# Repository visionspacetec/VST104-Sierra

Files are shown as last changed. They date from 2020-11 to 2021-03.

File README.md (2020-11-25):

# VST104 Board Sierra - single MCU OBC for PC104
This repository contains the KiCad project and other documents created during the development of Board Sierra under [VST104 project](https://github.com/visionspacetec/VST104/). This PC104 CubeSats module is a single redundant onboard computer designed to fulfill most space industry requirements.

<p align="center">
  <br>
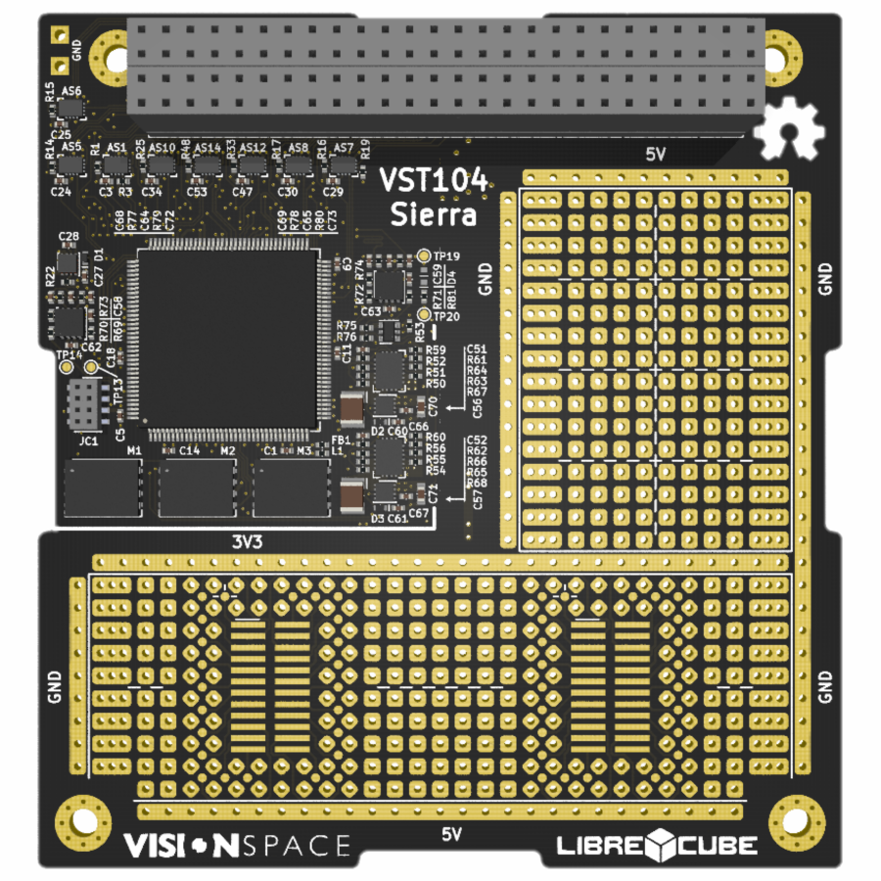
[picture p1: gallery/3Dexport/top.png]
  
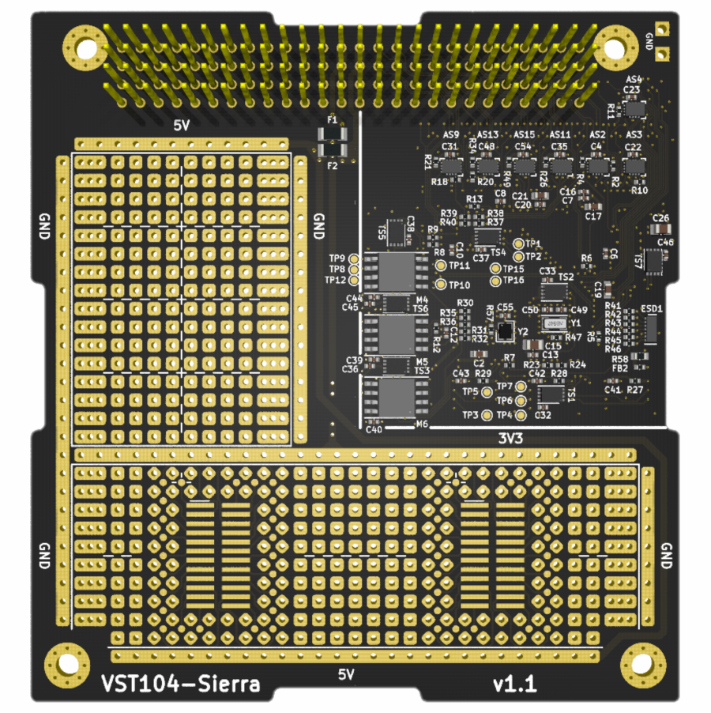
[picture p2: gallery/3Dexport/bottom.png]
  
  <br><br>
  <b>Fig 1.</b> Board Sierra OBC module 3D visualisation top (left) and bottom (right) side.
  <br><br>
</p>

## Basic specifications
* **`processor:`** This onboard computer is driven by state of the art, ultra-low-power **STM32L496 ARM® Cortex®-M4 core** microcontroller. This MCU is capable of running **up to 78[MHz]** in our design.
* **`clock:`** Microcontroller is driven by two external clock sources. Low-speed **external 32.768[kHz] oscillator** (LSE) and high-speed **external 26[MHz] oscillator** (HSE). The MCU is capable of temporarily disable the HSE to achieve better power consumption.
* **`memory:`** Two groups of triple redundant external memories are available for data storage and processing. The triple redundancy was chosen as an effective measure against single event effects. The first memory group is **256 [Mbit] Flash** wired via Quad-SPI interface and the second one is **2 [Mbit] F-RAM** using SPI.
* **`peripherals:`** This module can communicate with other CubeSat subsystems using a wide variety of redundant protocols. The main PC104 header is capable of connecting to **2x CAN-BUS, 3x I2C, 4x UART** (with CTS and RTS), **2xSPI** (2 enables each), and **22 general purpose** A/D I/O pins. All of the listed peripherals are wired thru separated isolators controlled by the MCU. On top of that, separate traces are used for system check and maintenance signals, such as: WatchDog, KillSwitch, CPUmode, Sync, FaultCollector. The pinout of these interferences is shown in figure 3.
* **`connectivity:`** A user can program and debug this OBC using **SWI and/or UART interface**. These interfaces are accessible on the board's edge on a separate connector with integrated electrostatic discharge protection circuitry. The SWI interface is compatible with STM ST-LINK series programmers (including SWO pin).

<p align="center">
  <br>
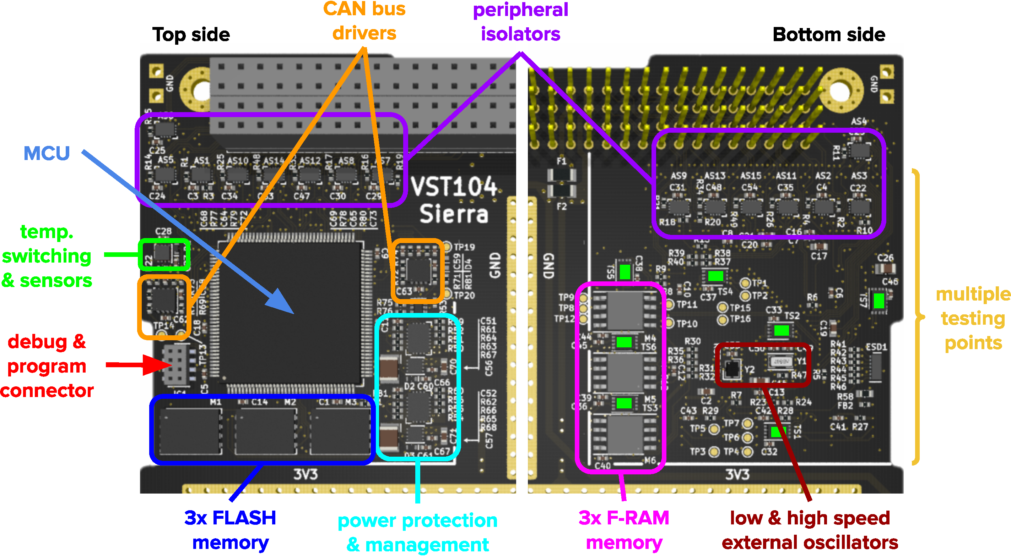
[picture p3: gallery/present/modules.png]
  
  <br><br>
  <b>Fig 2.</b> Important circuitry groups on top (left) and bottom (right) side of the module.
  <br><br>
</p>

## Features
* All used components are suitable for the space environment, following: mechanical failure qualifications **AEC-Q100 or AEC-Q200** and **military rated** operational temperatures (-40°C to +125°C).
* This module requires two separate power lines of 3.3[V] and 5[V] ratings. A **robust power management** circuitry is present separately on these lines, providing various functionalities. Namely: tunable over and under-voltage protection, tunable over-current protection, amplified current monitoring output, kill switching, or simultaneous power down.
* A group of **seven I2C temperature sensors** is spread over the entire module. These sensors are used to check the temperature of essential submodules such as: 2x power management, 2x CAN-BUS drivers, 2x external memories, and 1x STM32 microcontroller. Also, the MCU can power these sensors in case of power saving or latch-up events.
* A compact design was one of our priorities during the development of this module. As a result, this module's full three-fourths are left empty and ready to **accommodate any required payload**. This current version is the payload sector represented as a universal soldering array with exposed power lines (outside the power management).

<p align="center">
  <br>
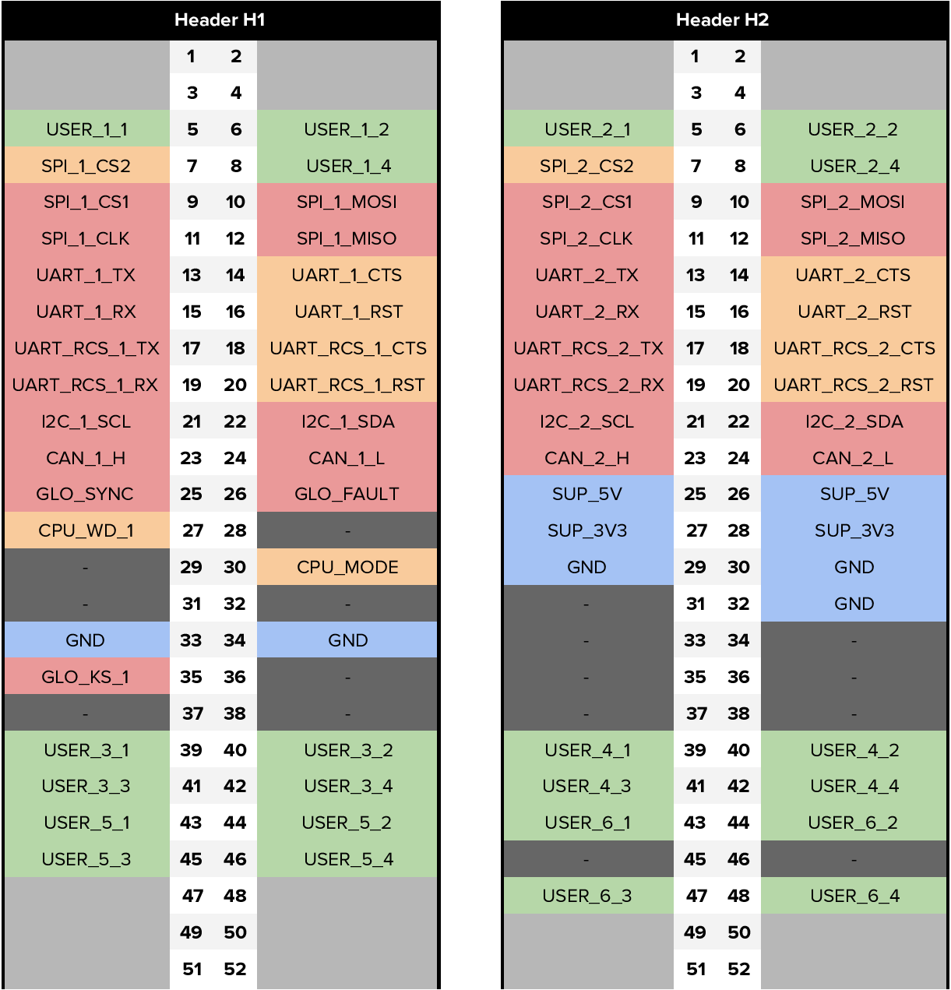
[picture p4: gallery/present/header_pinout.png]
  
  <br><br>
  <b>Fig 3.</b> PC104 header pinout supported by this OBC module.
  <br><br>
</p>

## Debug & Program connector
A separate 2x4 female format connector on the board's left side is used for debugging and programming.  SWI and UART5 interfaces of the boarded STM32 microprocessor are wired to this connector, as shown in figure 4. This interface is fully compatible with STM ST-Link family programmers. 

<p align="center">
  <br>
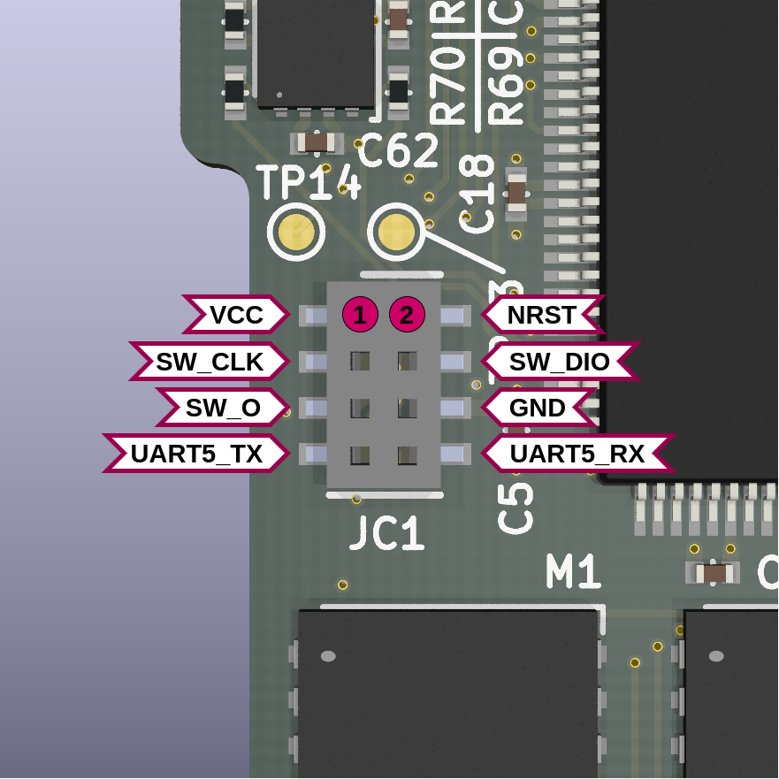
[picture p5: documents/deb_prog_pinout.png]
  
  <br><br>
  <b>Fig 4.</b> Pinout of the debug and program connector.
  <br><br>
</p>

## References
The design of this PC 104 SBC module was processed under evaluation of the following documents:

[1] : [STM32L496xx datasheet](https://www.st.com/resource/en/datasheet/stm32l496ae.pdf)  
[2] : [STM32L496xx getting started manual](https://www.st.com/resource/en/application_note/dm00125306-getting-started-with-stm32l4-series-and-stm32l4-series-hardware-development-stmicroelectronics.pdf)  
[3] : [STM32 oscillator design guide](https://www.st.com/resource/en/application_note/cd00221665-oscillator-design-guide-for-stm8afals-stm32-mcus-and-mpus-stmicroelectronics.pdf)  
[4] : [STM32 Quad-SPI interface](https://www.st.com/resource/en/application_note/dm00227538-quadspi-interface-on-stm32-microcontrollers-and-microprocessors-stmicroelectronics.pdf)  
[5] : [Common mode chokes in CAN networks](https://www.ti.com/lit/an/slla271/slla271.pdf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,results%20in%20the%20CAN%20network.&text=Following%20the%20choke%20in%20the,is%20the%20optional%20termination%20circuit.)  
[6] : [Isolated CAN systems with protection](https://www.ti.com/lit/an/slla419/slla419.pdf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,ratings%20up%20to%20several%20kilowatts.)

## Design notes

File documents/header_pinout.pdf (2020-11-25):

Header H1 | | Header H2
| 1 2 | | | 1 2
| 3 4 | | | 3 4
USER_1_1 | 5 6 | USER_1_2 | USER_2_1 | 5 6 | USER_2_2
SPI_1_CS2 | 7 8 | USER_1_4 | SPI_2_CS2 | 7 8 | USER_2_4
SPI_1_CS1 | 9 | 10 | SPI_1_MOSI | SPI_2_CS1 | 9 | 10 | SPI_2_MOSI
SPI_1_CLK | 11 | 12 | SPI_1_MISO | SPI_2_CLK | 11 | 12 | SPI_2_MISO
UART_1_TX | 13 | 14 | UART_1_CTS | UART_2_TX | 13 | 14 | UART_2_CTS
UART_1_RX | 15 | 16 | UART_1_RST | UART_2_RX | 15 | 16 | UART_2_RST
UART_RCS_1_TX | 17 | 18 | UART_RCS_1_CTS | UART_RCS_2_TX | 17 | 18 | UART_RCS_2_CTS
UART_RCS_1_RX | 19 20 | UART_RCS_1_RST | UART_RCS_2_RX | 19 20 | UART_RCS_2_RST
I2C_1_SCL | 21 22 | I2C_1_SDA | I2C_2_SCL | 21 22 | I2C_2_SDA
CAN_1_H | 23 24 | CAN_1_L | CAN_2_H | 23 24 | CAN_2_L
GLO_SYNC | 25 26 | GLO_FAULT | SUP_5V | 25 26 | SUP_5V
CPU_WD_1 | 27 28 | - | SUP_3V3 | 27 28 | SUP_3V3
-- | 29 30 | CPU_MODE | GND | 29 30 | GND
| 31 32 | - | - | 31 32 | GND
GND | 33 34 | GND | - | 33 34 | -
GLO_KS_1 | 35 36 | - | - | 35 36 | -
- | 37 38 | - | - | 37 38 | -
USER_3_1 USER_3_3 USER_5_1 USER_5_3 | 39 40 | USER_3_2 | USER_4_1 | 39 40 | USER_4_2
| 41 42 | USER_3_4 | USER_4_3 | 41 42 | USER_4_4
| 43 44 | USER_5_2 | USER_6_1 | 43 44 | USER_6_2
| 45 46 | USER_5_4 | - | 45 46 | -
| 47 48 | | USER_6_3 | 47 48 | USER_6_4
| 49 50 | | | 49 50
| 51 52 | | | 51 52

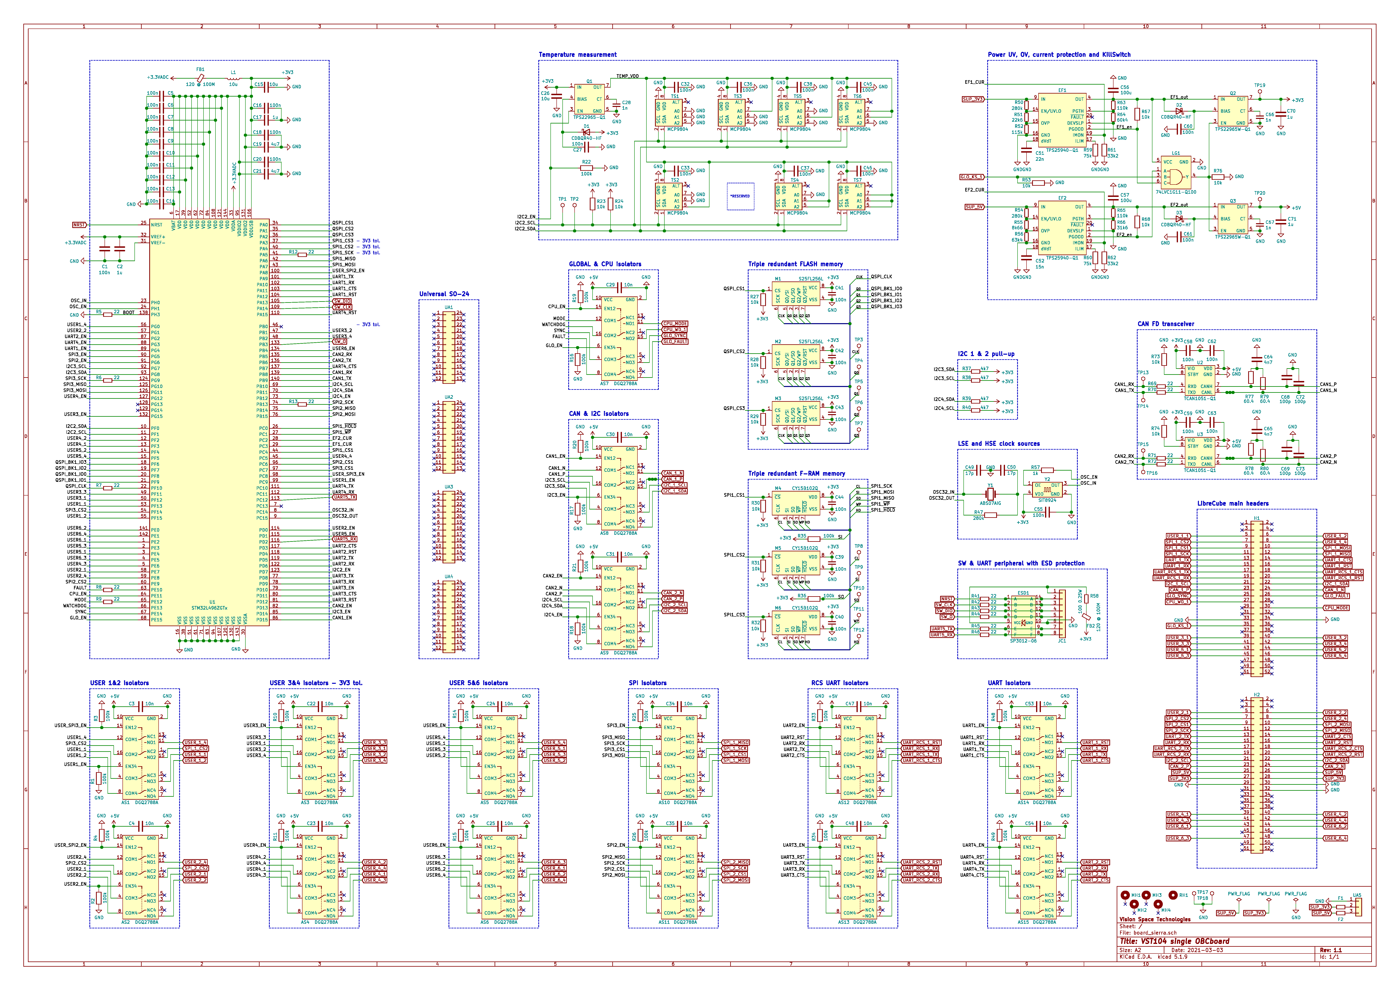
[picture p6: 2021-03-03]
gallery/present/schematic.png

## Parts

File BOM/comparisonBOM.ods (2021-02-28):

 |  |  |  | Temperature and automotive certified |  |  |  | Uncertified replacement/variant
customer no | description | schematic | qty. | manufacturer no | Mouser no | price | ext. | manufacturer no | Mouser no | price | ext. | delta | type | main differences
mcu | microcontroller | U1 | 1 | STM32L496ZGT3 | 511-STM32L496ZGT3 | 11.51 | 11.51 | STM32L496ZGT3 | 511-STM32L496ZGT3 | 11.51 | 11.51 | 0 | same | N/A
clo_lse | LSE crystal | Y1 | 1 | ABS07AIG-32.768kHz-6-1-T | 815-S07AIG32.768-61T | 0.983 | 0.983 | SC32S-7PF20PPM | 628-SC32S-7PF20PPM | 0.382 | 0.382 | -0.601 | repl. | capacitance, tolerance, qual.
clo_hse | HSE oscillator | Y2 | 1 | SIT8924AA-72-XXE-26.000000G | 788-8924AA-72XXE26G | 2.68 | 2.68 | MC2016Z26.0000C19XSH | 346-MC2016Z26.0000C1 | 1.14 | 1.14 | -1.54 | repl. | stability, qual.
per_tmp | temperature sen. | TS* | 7 | MCP9804-E/MC | 579-MCP9804-E/MC | 1.42 | 9.94 | MCP9808T-E/MC | 579-MCP9808T-E/MC | 0.957 | 6.699 | -3.241 | variant | accuracy
per_isol | analog isolator | AS* | 15 | DGQ2788AEN-T1-GE4 | 78-DGQ2788AEN-T1-GE4 | 0.688 | 10.32 | DGQ2788AEN-T1-GE4 | 78-DGQ2788AEN-T1-GE4 | 0.688 | 10.32 | 0 | same | N/A
per_can | CAN bus driver | U[2,3] | 2 | TCAN1051GVDRBRQ1 | 595-TCAN1051GVDRBRQ1 | 0.949 | 1.898 | TCAN1051GVDRBRQ1 | 595-TCAN1051GVDRBRQ1 | 0.949 | 1.898 | 0 | same | N/A
per_flash | FLASH memory | M[1-3] | 3 | S25FL256LAGNFB010 | 727-S25FL256LANFB010 | 4.1 | 12.3 | S25FL256LAGNFI010 | 727-S25FL256LAGNFI00 | 2.72 | 8.16 | -4.14 | variant | power, qual.
per_conn | prog. connector | JC1 | 1 | CLP-104-02-F-D | 200-CLP10402FD | 1.41 | 1.41 | CLP-104-02-F-D | 200-CLP10402FD | 1.41 | 1.41 | 0 | same | N/A
pow_efus | E-Fuse | EF[1,2] | 2 | TPS25940AQRVCRQ1 | 595-TPS25940AQRVCRQ1 | 1.95 | 3.9 | TPS25940ARVCR | 595-TPS25940ARVCR | 1.65 | 3.3 | -0.600000000000001 | variant | qual.
pow_swit | hot-side switch | Q[1-3] | 3 | TPS22965QWDSGRQ1 | 595-TPS22965QWDSGRQ1 | 0.915 | 2.745 | TPS22975DSGR | 595-TPS22975DSGR | 0.44 | 1.32 | -1.425 | variant | current, resistance, timing, qual.
pow_gate | logic gate | LG1 | 1 | 74LVC1G11GW-Q100H | 771-74LVC1G11GWQ100H | 0.296 | 0.296 | 74LVC1G11GW,125 | 771-LVC1G11GW125 | 0.254 | 0.254 | -0.042 | variant | current, timing, qual.
pow_esd | ESD protection | ESD1 | 1 | SP3012-06UTG | 576-SP3012-06UTG | 0.889 | 0.889 | SP3012-06UTG | 576-SP3012-06UTG | 0.889 | 0.889 | 0 | same | N/A
pow_febe | ferrite bead | FB[1,2] | 2 | MMZ1005Y121CTD25 | 810-MMZ1005Y121CTD25 | 0.085 | 0.17 | MMZ1005Y121CTD25 | 810-MMZ1005Y121CTD25 | 0.085 | 0.17 | 0 | same | N/A
pow_indu | inductor | L1 | 1 | MLZ1608N100LTD25 | 810-MLZ1608N100LTD25 | 0.169 | 0.169 | MLZ1608E100M | 810-MLZ1608E100M | 0.102 | 0.102 | -0.067 | variant | current, resistence, qual.
dio_schot | Schottky diode | D[1-3] | 3 | CDBQR40-HF | 750-CDBQR40-HF | 0.305 | 0.915 | CDBQR0230R-HF | 750-CDBQR0230R-HF | 0.263 | 0.789 | -0.126 | variant | forward voltage, qual.
 |  |  |  |  |  | SUM | 60.125 |  |  | SUM | 48.343 | -11.782
N/A | resisotrs & capacitors | R*, C* |  | N/A | N/A | N/A | N/A | various components | N/A | N/A | 10.86 | N/A | N/A | N/A
 |  |  |  |  |  | FINAL | - |  |  | FINAL | 59.203 | -

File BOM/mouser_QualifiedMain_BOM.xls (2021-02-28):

BOARD SIERRA - UNQUALIFIED, RC
Mouser No | Mfr. No | Manufacturer | Customer No | Description | RoHS | Lifecycle | Order Qty. | Price (EUR) | Ext.: (EUR)
81-GCM155R71H104KE2J | GCM155R71H104KE02J | Murata |  | Multilayer Ceramic Capacitors MLCC - SMD/SMT 0402 0.1uF 50volts X7R 10% | RoHS Compliant |  | 35 | 0,026 € | 0,91 €
81-GCM1555C1H101JA6D | GCM1555C1H101JA16D | Murata |  | Multilayer Ceramic Capacitors MLCC - SMD/SMT 0402 100pF 50volts C0G 5% | RoHS Compliant |  | 4 | 0,085 € | 0,34 €
81-GCM1555C1H102JA6J | GCM1555C1H102JA16J | Murata |  | Multilayer Ceramic Capacitors MLCC - SMD/SMT 0402 1000pF 50volts C0G 5% | RoHS Compliant |  | 3 | 0,085 € | 0,26 €
81-GCM155R72A472JA7J | GCM155R72A472JA37J | Murata |  | Multilayer Ceramic Capacitors MLCC - SMD/SMT 0402 4700pF 100volts X7R 5% | RoHS Compliant |  | 2 | 0,085 € | 0,17 €
81-GCQ1555C1H170JB1D | GCQ1555C1H170JB01D | Murata |  | Multilayer Ceramic Capacitors MLCC - SMD/SMT 0402 50VDC 17pF 5% AEC-Q200 | RoHS Compliant |  | 2 | 0,271 € | 0,54 €
81-GCM155R71H153JA5D | GCM155R71H153JA55D | Murata |  | Multilayer Ceramic Capacitors MLCC - SMD/SMT 0402 0.015uF 50volts X7R 5% | RoHS Compliant |  | 1 | 0,085 € | 0,09 €
81-GCM155R71H223JA5D | GCM155R71H223JA55D | Murata |  | Multilayer Ceramic Capacitors MLCC - SMD/SMT 0402 0.022uF 50volts X7R 5% | RoHS Compliant |  | 1 | 0,085 € | 0,09 €
81-GCM155R71H103JA5D | GCM155R71H103JA55D | Murata |  | Multilayer Ceramic Capacitors MLCC - SMD/SMT 0402 0.01uF 50volts X7R 5% | RoHS Compliant |  | 15 | 0,041 € | 0,62 €
81-GRT21BC71E106KE13 | GRT21BC71E106KE13L | Murata |  | Multilayer Ceramic Capacitors MLCC - SMD/SMT | RoHS Compliant |  | 2 | 0,508 € | 1,02 €
667-ERJ-2RKF1002X | ERJ-2RKF1002X | Panasonic |  | Thick Film Resistors - SMD 0402 10Kohms 1% AEC-Q200 | RoHS Compliant By Exemption |  | 14 | 0,019 € | 0,27 €
667-ERJ-2RKF1003X | ERJ-2RKF1003X | Panasonic |  | Thick Film Resistors - SMD 0402 100Kohms 1% AEC-Q200 | RoHS Compliant By Exemption |  | 23 | 0,023 € | 0,53 €
667-ERJ-2RKF7502X | ERJ-2RKF7502X | Panasonic |  | Thick Film Resistors - SMD 0402 75Kohms 1% AEC-Q200 | RoHS Compliant By Exemption |  | 2 | 0,085 € | 0,17 €
667-ERJ-2RKF60R4X | ERJ-2RKF60R4X | Panasonic |  | Thick Film Resistors - SMD 0402 60.4ohms 1% AEC-Q200 | RoHS Compliant By Exemption |  | 4 | 0,085 € | 0,34 €
667-ERJ-2RKF4701X | ERJ-2RKF4701X | Panasonic |  | Thick Film Resistors - SMD 0402 4.7Kohms 1% AEC-Q200 | RoHS Compliant By Exemption |  | 4 | 0,085 € | 0,34 €
667-ERJ-2RKF1103X | ERJ-2RKF1103X | Panasonic |  | Thick Film Resistors - SMD 0402 110Kohms 1% AEC-Q200 | RoHS Compliant By Exemption |  | 2 | 0,085 € | 0,17 €
667-ERJ-2RKF2803X | ERJ-2RKF2803X | Panasonic |  | Thick Film Resistors - SMD 0402 280Kohms 1% AEC-Q200 | RoHS Compliant By Exemption |  | 3 | 0,085 € | 0,26 €
667-ERJ-2RKF22R0X | ERJ-2RKF22R0X | Panasonic |  | Thick Film Resistors - SMD 0402 22.0ohms 1% Tol AEC-Q200 | RoHS Compliant By Exemption |  | 17 | 0,019 € | 0,32 €
667-ERJ-U02F2262X | ERJ-U02F2262X | Panasonic |  | Thick Film Resistors - SMD 0402 1% 22.6Kohm Anti-Sulfur AEC-Q200 | RoHS Compliant By Exemption |  | 1 | 0,085 € | 0,09 €
667-ERJ-2RKF1153X | ERJ-2RKF1153X | Panasonic |  | Thick Film Resistors - SMD 0402 115Kohms 1% AEC-Q200 | RoHS Compliant By Exemption |  | 1 | 0,085 € | 0,09 €
667-ERJ-2RKF8661X | ERJ-2RKF8661X | Panasonic |  | Thick Film Resistors - SMD 0402 8.66Kohms 1% AEC-Q200 | RoHS Compliant By Exemption |  | 1 | 0,085 € | 0,09 €
667-ERJ-2RKF6342X | ERJ-2RKF6342X | Panasonic |  | Thick Film Resistors - SMD 0402 63.4Kohms 1% AEC-Q200 | RoHS Compliant By Exemption |  | 1 | 0,085 € | 0,09 €
667-ERJ-2RKF3162X | ERJ-2RKF3162X | Panasonic |  | Thick Film Resistors - SMD 0402 31.6Kohms 1% AEC-Q200 | RoHS Compliant By Exemption |  | 1 | 0,085 € | 0,09 €
667-ERJ-2RKF1001X | ERJ-2RKF1001X | Panasonic |  | Thick Film Resistors - SMD 0402 1Kohms 1% AEC-Q200 | RoHS Compliant By Exemption |  | 1 | 0,085 € | 0,09 €
667-ERJ-U02F6042X | ERJ-U02F6042X | Panasonic |  | Thick Film Resistors - SMD 0402 1% 60.4Kohm Anti-Sulfur AEC-Q200 | RoHS Compliant By Exemption |  | 1 | 0,085 € | 0,09 €
530-C1Q750 | C1Q 750 | Bel | uni. array fuse | Surface Mount Fuses 1206 SMT Fuse VeryFastActing 750mA | RoHS Compliant |  | 2 | 0,237 € | 0,47 €
755-ESR03EZPJ101 | ESR03EZPJ101 | ROHM Semiconductor |  | Thick Film Resistors - SMD 0603 100ohm 5% Anti Surge AEC-Q200 | RoHS Compliant |  | 1 | 0,085 € | 0,09 €
81-GCJ188R71E105KA1D | GCJ188R71E105KA01D | Murata |  | Multilayer Ceramic Capacitors MLCC - SMD/SMT 0603 1uF 25volts X7R 10% Soft Term | RoHS Compliant |  | 4 | 0,237 € | 0,95 €
81-GRT188C81E475KE3D | GRT188C81E475KE13D | Murata |  | Multilayer Ceramic Capacitors MLCC - SMD/SMT 0603 25Vdc 4.7uF X6S 10% | RoHS Compliant |  | 2 | 0,432 € | 0,86 €
667-ERJ-2RKF3322X | ERJ-2RKF3322X | Panasonic |  | Thick Film Resistors - SMD 0402 33.2Kohms 1% AEC-Q200 | RoHS Compliant By Exemption |  | 2 | 0,085 € | 0,17 €
581-TAJB107M010R | TAJB107M010RNJ | AVX |  | Tantalum Capacitors - Solid SMD 10V 100uF 1210 ESR=1.4Ohms 20% | RoHS Compliant |  | 2 | 0,627 € | 1,25 €

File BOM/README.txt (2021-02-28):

None of the Mouser BOMs or BOMs comparison include the F-RAM chip.
You can find the component on MOUSER under this link:
https://www.mouser.sk/ProductDetail/Cypress-Semiconductor/CY15B102Q-SXE/?qs=3FnuM6ZipRLKWyrfsFIJqQ%3D%3D

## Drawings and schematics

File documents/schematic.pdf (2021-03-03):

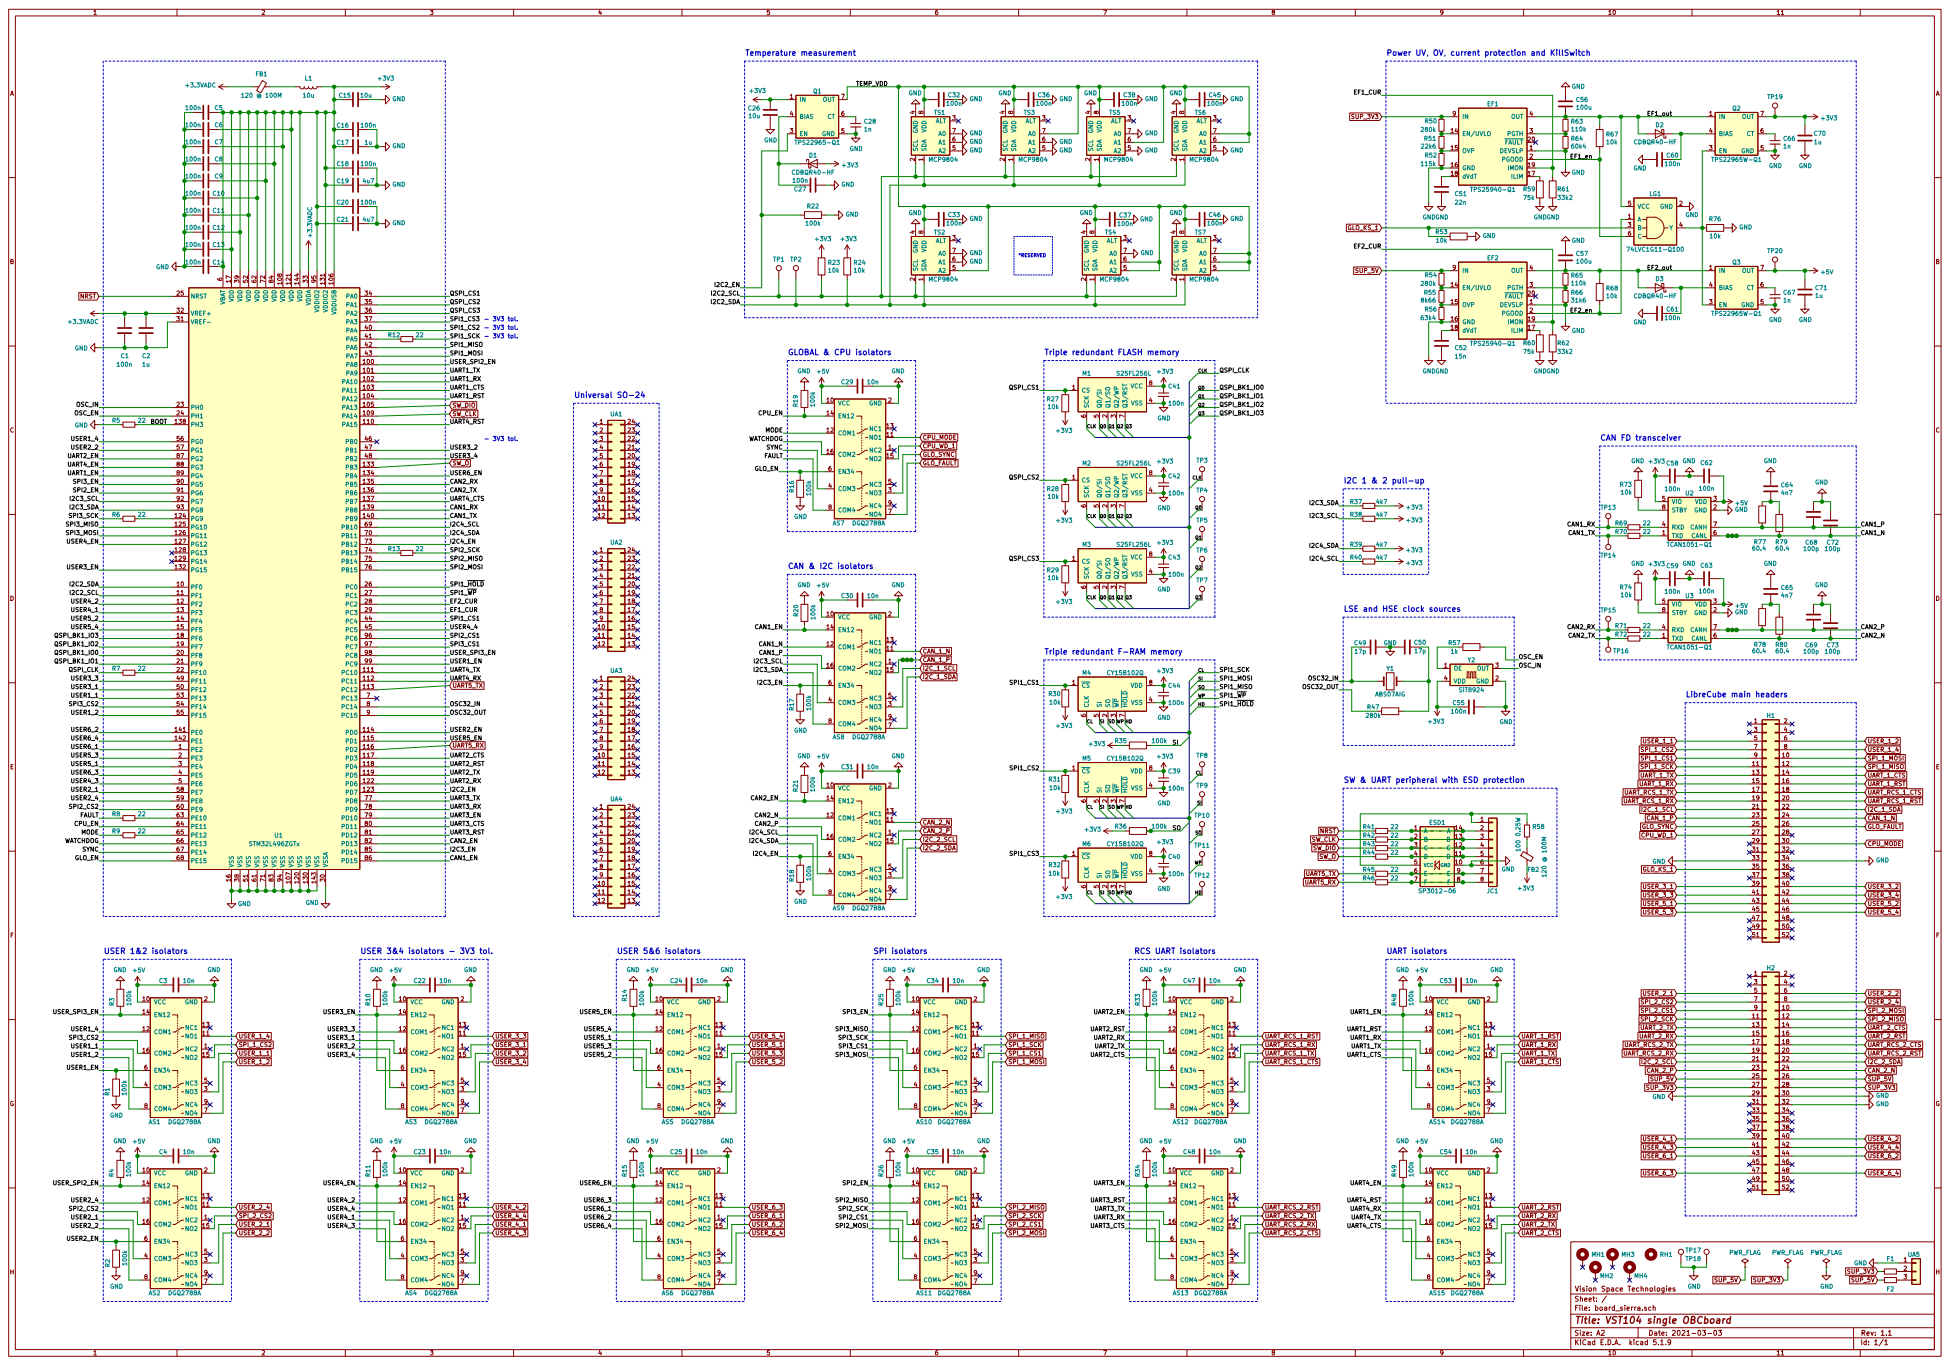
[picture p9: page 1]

Power UV, OV, current protection and KillSwitch

8TS6 MCP9804 GND GND GND GND GND GND GND GND GND SDA

6 VDD 108 VDD 121 VDD 144 VDD 17 VDD 39 VDD 52 VDD 62 VDD 72 VDD 84 VDDA 33 VDDIO2 131 VDDIO2 95 VDDUSB 106 VREF+ 32 VREF- 31 VSS 107 VSS 120 VSS 130 VSS 143 VSS 16 VSS 38 VSS 51 VSS 61 VSS 71 VSS 83 VSS 94 VSSA 30 U1 STM32L496ZGTx GND GND R34 100k GND

EF2_en Triple redundant F-RAM memory

Triple redundant FLASH memory

LSE and HSE clock sources

SW & UART peripheral with ESD protection

File: board_sierra.sch Sheet: / Vision Space Technologies

Id: 1/1 Title: VST104 single OBCboard

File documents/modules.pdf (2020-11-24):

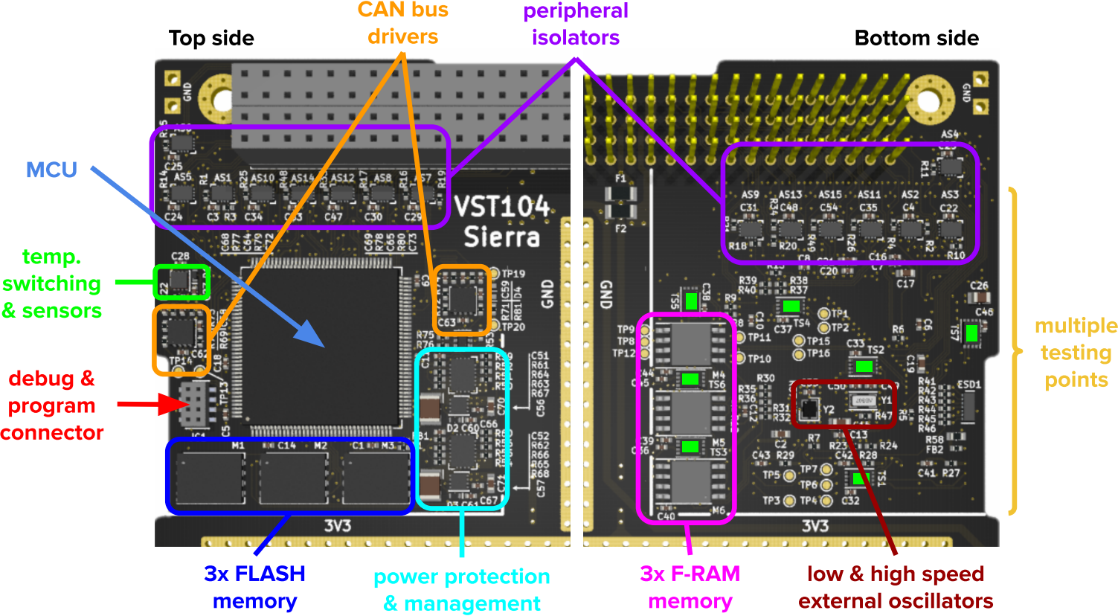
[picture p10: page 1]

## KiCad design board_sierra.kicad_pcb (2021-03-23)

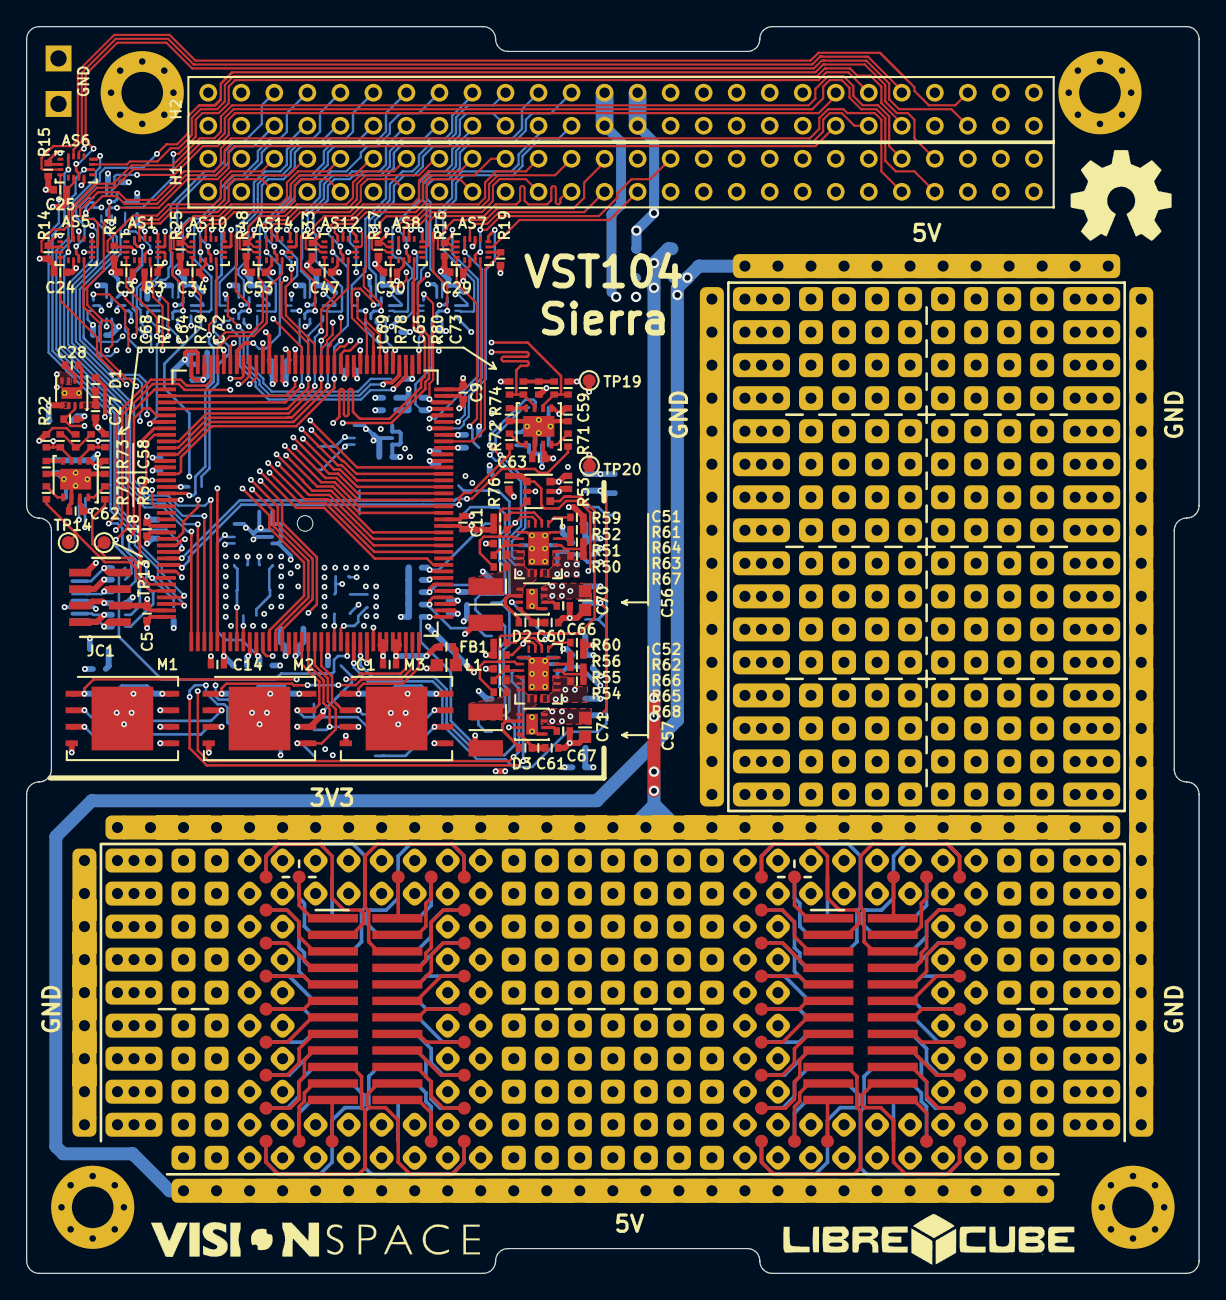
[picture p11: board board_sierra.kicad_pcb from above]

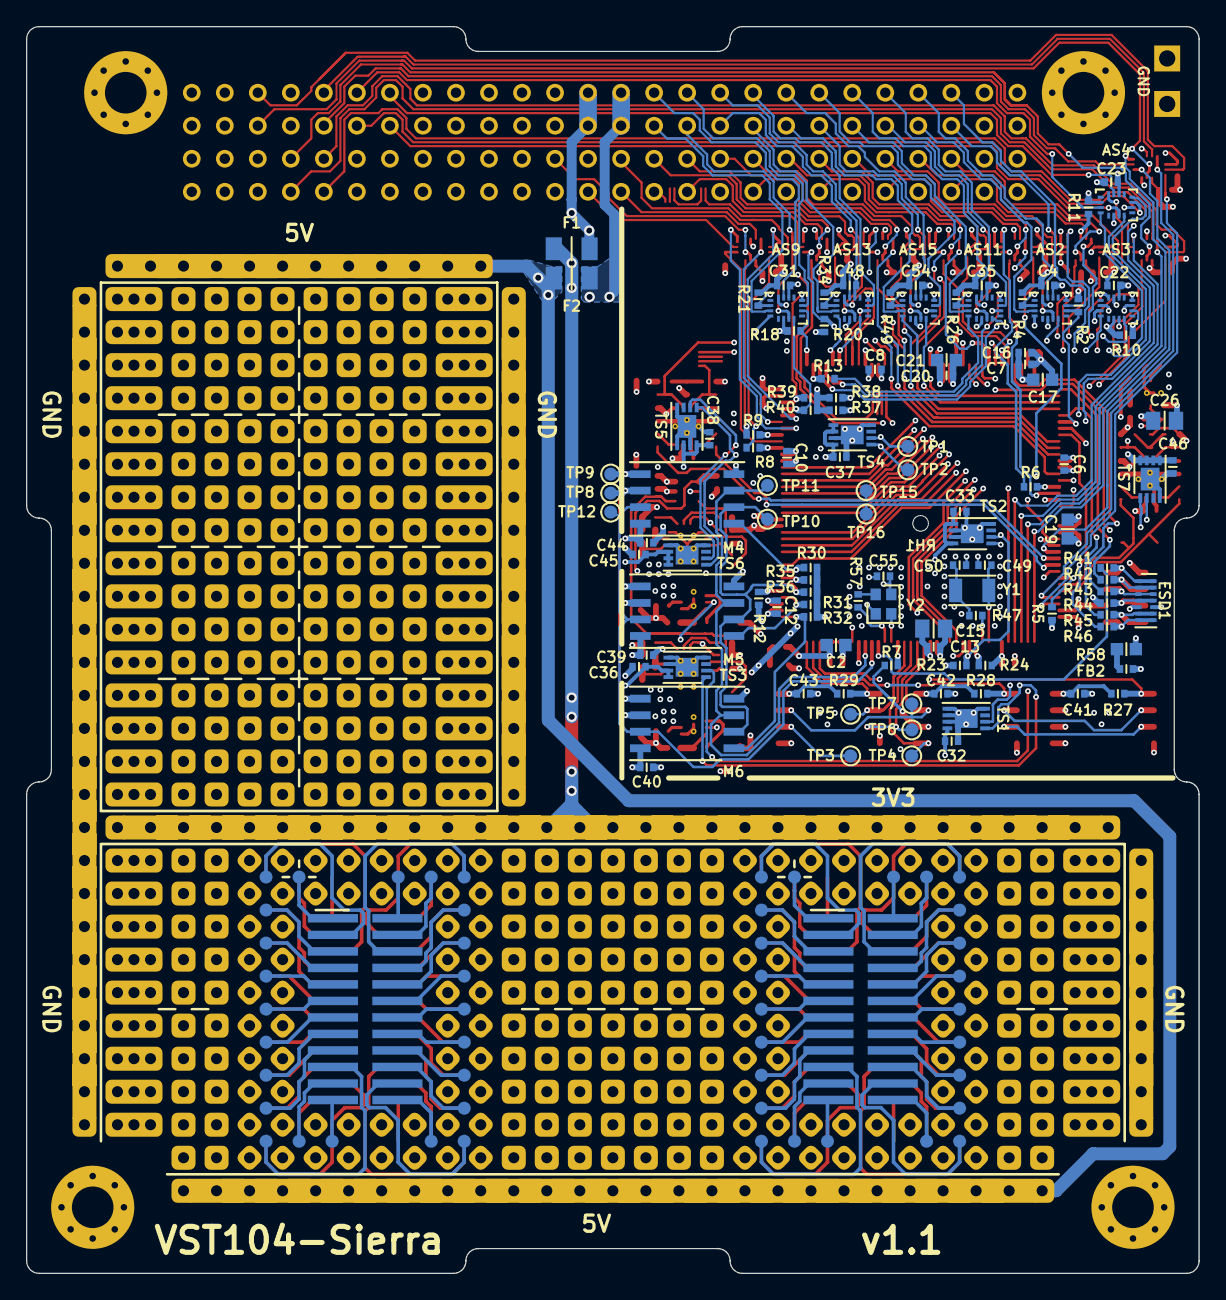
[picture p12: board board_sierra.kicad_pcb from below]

Board: 6 copper layers, 90.2 x 95.9 mm, 245 parts (116 on the bottom side), 232 nets.

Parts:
AS1, AS2, AS3, AS4, AS5, AS6, AS7, AS8, AS9, AS10, AS11, AS12, AS13, AS14, AS15: DGQ2788A; mini_QFN-16-1.8x2.6mm
C1, C5, C6, C7, C8, C9, C10, C11, C12, C13, C14, C16, C18, C20, C27, C32, C33, C36, C37, C38, C39, C40, C41, C42, C43, C44, C45, C46, C55, C58, C59, C60, C61, C62, C63: 100n; C_SMD_0402
C2, C17, C70, C71: 1u; C_SMD_0603
C3, C4, C22, C23, C24, C25, C29, C30, C31, C34, C35, C47, C48, C53, C54: 10n; C_SMD_0402
C15, C26: 10u; C_SMD_0805
C19, C21: 4u7; C_SMD_0603
C28, C66, C67: 1n; C_SMD_0402
C49, C50: 17p; C_SMD_0402
C51: 22n; C_SMD_0402
C52: 15n; C_SMD_0402
C56, C57: 100u; C_SMD_1210
C64, C65: 4n7; C_SMD_0402
C68, C69, C72, C73: 100p; C_SMD_0402
D1, D2, D3: Schottky diode; D_SMD_0402
EF1, EF2: TPS25940-Q1; WQFN-20_4.0x3.0mm_EPV
ESD1: SP3012-06; uDFN-14_3.5x1.35mm
F1, F2: 0; R_SMD_1206
FB1, FB2: 120@100M; R_SMD_0402
H1, H2: Conn_02x26_Odd_Even; ESQ-126-39-x-D
JC1: SW&UART; CLP-104-02-x-D
L1: 10u; L_SMD_0603
LG1: 74LVC1G11-Q100; SOT-363_TSSOP-6_2.0x1.25mm
LOGO1: logo; VST_logo_horizontal_700
LOGO2: logo; LibreCube_logo_22.4mm
LOGO3: logo; OSH_logo_8mm
M1, M2, M3: S25FL256L; WSON-8_6.0x8.0mm_EP
M4, M5, M6: CY15B102Q; SOIC-8_208_5.23x5.23mm
MH1, MH2, MH3, MH4: MountingHole_Pad; MountingHole_3.2mm_M3_Pad_Via
Q1: TPS22965-Q1; WSON-8_2.0x2.0mm_EPV
Q2, Q3: TPS22965W-Q1; WSON-8_2.0x2.0mm_EPV
R1, R2, R3, R4, R10, R11, R14, R15, R16, R17, R18, R19, R20, R21, R22, R25, R26, R33, R34, R35, R36, R48, R49: 100k; R_SMD_0402
R5, R23, R24, R27, R28, R29, R30, R31, R32, R53, R67, R68, R73, R74, R76: 10k; R_SMD_0402
R6, R7, R8, R9, R12, R13, R41, R42, R43, R44, R45, R46, R69, R70, R71, R72: 22; R_SMD_0402
R37, R38, R39, R40: 4k7; R_SMD_0402
R47, R50, R54: 280k; R_SMD_0402
R51: 22k6; R_SMD_0402
R52: 115k; R_SMD_0402
R55: 8k66; R_SMD_0402
R56: 63k4; R_SMD_0402
R57: 1k; R_SMD_0402
R58: 100 0.25W; R_SMD_0603
R59, R60: 75k; R_SMD_0402
R61, R62: 33k2; R_SMD_0402
R63, R65: 110k; R_SMD_0402
R64: 60k4; R_SMD_0402
R66: 31k6; R_SMD_0402
R77, R78, R79, R80: 60.4; R_SMD_0402
RH1: ResinHole; MountingHole_1.2mm
TP1, TP2, TP3, TP4, TP5, TP6, TP7, TP8, TP9, TP10, TP11, TP12, TP13, TP14, TP15, TP16, TP19, TP20: test_point; scope_PAD_1mm
TP17, TP18: GND; scope_GND
TRC1, TRC2, TRC3: trace_0.173mm; trace_arc_0.173mm
TRC4, TRC5, TRC6, TRC7, TRC8, TRC9: trace_0.2mm; trace_arc_0.2mm
TS1, TS2, TS3, TS4, TS5, TS6, TS7: MCP9804; DFN-8_3.0x2.0mm_EP
U1: STM32L496ZGTx; LQFP-144_20x20mm_P0.5mm
U2, U3: TCAN1051-Q1; VSON-8_3.0x3.0mm_EPV
UA1, UA2, UA3, UA4: PC104_SO-24_universal
UA5: Conn_01x03; PC104_universal_OBC&FPGA
Y1: ABS07AIG; LSE_3.2x1.5mm
Y2: SiT8924; HSE_2.0x1.6mm

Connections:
+3.3VADC: C1.2, C2.2, FB1.2, U1.32, U1.33
+3V3: C5.2, C6.2, C7.2, C8.2, C9.2, C10.2, C11.2, C12.2, C13.2, C14.2, C15.1, C16.2, C17.2, C18.2, C19.2, C20.2, C21.2, C26.2, C39.1, C40.1, C41.1, C42.1, C43.1, C44.1, C55.2, C58.2, C59.2, C70.2, D1.2, FB2.2, L1.1, M1.8, M2.8, M3.8, M4.8, M5.8, M6.8, Q1.1, Q1.2, Q2.7, Q2.8, R23.1, R24.1, R27.1, R28.1, R29.1, R30.1, R31.1, R32.1, R35.1, R36.1, R37.1, R38.1, R39.1, R40.1, TP19.1, U1.6, U1.17, U1.39, U1.52, U1.62, U1.72, U1.84, U1.95, U1.106, U1.108, U1.121, U1.131, U1.144, U2.5, U3.5, Y2.4
+5V: AS1.10, AS2.10, AS3.10, AS4.10, AS5.10, AS6.10, AS7.10, AS8.10, AS9.10, AS10.10, AS11.10, AS12.10, AS13.10, AS14.10, AS15.10, C3.2, C4.2, C22.2, C23.2, C24.2, C25.2, C29.2, C30.2, C31.2, C34.2, C35.2, C47.2, C48.2, C53.2, C54.2, C62.2, C63.2, C71.2, Q3.7, Q3.8, TP20.1, U2.3, U3.3
/CAN1_EN: AS8.14, R20.2, U1.86
/CAN1_N: AS8.12, C72.2, R79.1, TRC4.1, TRC6.1, TRC8.1, U2.6
/CAN1_P: AS8.16, C68.2, R77.1, U2.7
/CAN1_RX: R69.2, TP13.1, U1.139
/CAN1_TX: R70.2, TP14.1, U1.140
/CAN2_EN: AS9.14, R21.1, U1.82
/CAN2_N: AS9.12, C73.2, R80.1, U3.6
/CAN2_P: AS9.16, C69.2, R78.1, TRC5.1, TRC7.1, TRC9.1, U3.7
/CAN2_RX: R71.2, TP15.1, U1.135
/CAN2_TX: R72.2, TP16.1, U1.136
/CL: M4.6, M5.6, M6.6, R12.1, TP8.1
/CLK: M1.6, M2.6, M3.6, R7.2, TP3.1
/CPU_EN: AS7.14, R19.1, U1.64
/EF1_CUR: EF1.19, R61.2, U1.29
/EF1_en: EF1.2, LG1.6, R67.2
/EF1_out: C56.1, D2.2, EF1.4, EF1.5, EF1.6, EF1.7, EF1.8, LG1.5, Q2.1, Q2.2, R63.1, R67.1
/EF2_CUR: EF2.19, R62.2, U1.28
/EF2_en: EF2.2, LG1.1, R68.2
/EF2_out: C57.1, D3.2, EF2.4, EF2.5, EF2.6, EF2.7, EF2.8, Q3.1, Q3.2, R65.1, R68.1
/FAULT: AS7.8, R8.2
/GLO_EN: AS7.6, R16.1, U1.68
/HD: M4.7, M5.7, M6.7, TP12.1, U1.26
/I2C2_EN: Q1.3, R22.1, U1.123
/I2C2_SCL: R23.2, TP1.1, TS1.2, TS2.2, TS3.2, TS4.2, TS5.2, TS6.2, TS7.2, U1.11
/I2C2_SDA: R24.2, TP2.1, TS1.1, TS2.1, TS3.1, TS4.1, TS5.1, TS6.1, TS7.1, U1.10
/I2C3_EN: AS8.6, R17.1, U1.85
/I2C3_SCL: AS8.4, R38.2, U1.92
/I2C3_SDA: AS8.8, R37.2, U1.93
/I2C4_EN: AS9.6, R18.1, U1.73
/I2C4_SCL: AS9.4, R40.2, U1.69
/I2C4_SDA: AS9.8, R39.2, U1.70
/MODE: AS7.12, R9.2
/NRST: R41.2, U1.25
/OSC32_IN: C49.1, U1.8, Y1.1
/OSC32_OUT: R47.2, U1.9
/OSC_EN: R57.1, U1.24
/OSC_IN: U1.23, Y2.3
/Q0: M1.5, M2.5, M3.5, TP4.1, U1.20
/Q1: M1.2, M2.2, M3.2, TP5.1, U1.21
/Q2: M1.3, M2.3, M3.3, TP6.1, U1.19
/Q3: M1.7, M2.7, M3.7, TP7.1, U1.18
/QSPI_CS1: M1.1, R27.2, U1.34
/QSPI_CS2: M2.1, R28.2, U1.35
/QSPI_CS3: M3.1, R29.2, U1.36
/SI: M4.5, M5.5, M6.5, R35.2, TP9.1, U1.43
/SO: M4.2, M5.2, M6.2, R36.2, TP10.1, U1.42
/SPI1_CS1: M4.1, R30.2, U1.44
/SPI1_CS2: M5.1, R31.2, U1.40
/SPI1_CS3: M6.1, R32.2, U1.37
/SPI1_~WP: M4.3, M5.3, M6.3, TP11.1, U1.27
/SPI2_CS1: AS11.4, U1.96
/SPI2_CS2: AS2.16, U1.60
/SPI2_EN: AS11.6, AS11.14, R26.1, U1.91
/SPI2_MISO: AS11.12, U1.75
/SPI2_MOSI: AS11.8, U1.76
/SPI2_SCK: AS11.16, R13.1
/SPI3_CS1: AS10.4, U1.97
/SPI3_CS2: AS1.16, U1.54
/SPI3_EN: AS10.6, AS10.14, R25.1, U1.90
/SPI3_MISO: AS10.12, U1.125
/SPI3_MOSI: AS10.8, U1.126
/SPI3_SCK: AS10.16, R6.2
/SW_CLK: R42.2, U1.109
/SW_DIO: R43.2, U1.105
/SW_O: R44.2, U1.133
/SYNC: AS7.4, U1.67
/TEMP_VDD: C32.1, C33.1, C36.1, C37.2, C38.1, C45.1, C46.1, Q1.7, Q1.8, TS1.8, TS2.5, TS2.8, TS3.7, TS3.8, TS4.5, TS4.6, TS4.8, TS5.6, TS5.8, TS6.6, TS6.7, TS6.8, TS7.5, TS7.6, TS7.7, TS7.8
/UART1_CTS: AS14.8, U1.103
/UART1_EN: AS14.6, AS14.14, R48.1, U1.89
/UART1_RST: AS14.12, U1.104
/UART1_RX: AS14.16, U1.102
/UART1_TX: AS14.4, U1.101
/UART2_CTS: AS12.8, U1.117
/UART2_EN: AS12.6, AS12.14, R33.1, U1.87
/UART2_RST: AS12.12, U1.118
/UART2_RX: AS12.16, U1.122
/UART2_TX: AS12.4, U1.119
/UART3_CTS: AS13.8, U1.80
/UART3_EN: AS13.6, AS13.14, R34.1, U1.79
/UART3_RST: AS13.12, U1.81
/UART3_RX: AS13.4, U1.78
/UART3_TX: AS13.16, U1.77
/UART4_CTS: AS15.8, U1.137
/UART4_EN: AS15.6, AS15.14, R49.1, U1.88
/UART4_RST: AS15.12, U1.110
/UART4_RX: AS15.16, U1.112
/UART4_TX: AS15.4, U1.111
/UART5_RX: R46.2, U1.116
/UART5_TX: R45.2, U1.113
/USER1_1: AS1.4, U1.53
/USER1_2: AS1.8, U1.55
/USER1_4: AS1.12, U1.56
/USER1_EN: AS1.6, R1.2, U1.99
/USER2_1: AS2.4, U1.58
/USER2_2: AS2.8, U1.57
/USER2_4: AS2.12, U1.59
/USER2_EN: AS2.6, R2.1, U1.114
/USER3_1: AS3.16, U1.50
/USER3_2: AS3.4, U1.47
/USER3_3: AS3.12, U1.49
/USER3_4: AS3.8, U1.48
/USER3_EN: AS3.6, AS3.14, R10.1, U1.132
/USER4_1: AS4.4, U1.13
/USER4_2: AS4.12, U1.12
/USER4_3: AS4.8, U1.5
/USER4_4: AS4.16, U1.45
/USER4_EN: AS4.6, AS4.14, R11.1, U1.127
/USER5_1: AS5.16, U1.3
/USER5_2: AS5.8, U1.14
/USER5_3: AS5.4, U1.2
/USER5_4: AS5.12, U1.15
/USER5_EN: AS5.6, AS5.14, R14.1, U1.115
/USER6_1: AS6.16, U1.1
/USER6_2: AS6.4, U1.141
/USER6_3: AS6.12, U1.4
/USER6_4: AS6.8, U1.142
/USER6_EN: AS6.6, AS6.14, R15.1, U1.134
/USER_SPI2_EN: AS2.14, R4.1, U1.100
/USER_SPI3_EN: AS1.14, R3.2, U1.98
/WATCHDOG: AS7.16, U1.66
CAN_1_N: AS8.11, H1.24
CAN_1_P: AS8.15, H1.23, TRC1.1, TRC2.1, TRC3.1
CAN_2_N: AS9.11, H2.24
CAN_2_P: AS9.15, H2.23
CPU_MODE: AS7.11, H1.30
CPU_WD_1: AS7.15, H1.27
GLO_FAULT: AS7.7, H1.26
GLO_KS_1: H1.35, LG1.3, R53.1
GLO_SYNC: AS7.3, H1.25
GND: AS1.2, AS2.2, AS3.2, AS4.2, AS5.2, AS6.2, AS7.2, AS8.2, AS9.2, AS10.2, AS11.2, AS12.2, AS13.2, AS14.2, AS15.2, C1.1, C2.1, C3.1, C4.1, C5.1, C6.1, C7.1, C8.1, C9.1, C10.1, C11.1, C12.1, C13.1, C14.1, C15.2, C16.1, C17.1, C18.1, C19.1, C20.1, C21.1, C22.1, C23.1, C24.1, C25.1, C26.1, C27.2, C28.2, C29.1, C30.1, C31.1, C32.2, C33.2, C34.1, C35.1, C36.2, C37.1, C38.2, C39.2, C40.2, C41.2, C42.2, C43.2, C44.2, C45.2, C46.2, C47.1, C48.1, C49.2, C50.1, C51.2, C52.2, C53.1, C54.1, C55.1, C56.2, C57.2, C58.1, C59.1, C60.2, C61.2, C62.1, C63.1, C64.1, C65.1, C66.2, C67.2, C68.1, C69.1, C70.1, C71.1, C72.1, C73.1, EF1.1, EF1.16, EF1.21, EF2.1, EF2.16, EF2.21, ESD1.10, H1.33, H1.34, H2.29, H2.30, H2.32, JC1.6, LG1.2, M1.4, M1.9, M2.4, M2.9, M3.4, M3.9, M4.4, M5.4, M6.4, Q1.5, Q1.9, Q2.5, Q2.9, Q3.5, Q3.9, R1.1, R2.2, R3.1, R4.2, R5.2, R10.2, R11.2, R14.2, R15.2, R16.2, R17.2, R18.2, R19.2, R20.1, R21.2, R22.2, R25.2, R26.2, R33.2, R34.2, R48.2, R49.2, R52.2, R53.2, R56.2, R59.1, R60.1, R61.1, R62.1, R64.2, R66.2, R73.2, R74.2, R76.2, TP17.1, TP18.1, TS1.4, TS1.5, TS1.6, TS1.7, TS1.9, TS2.4, TS2.6, TS2.7, TS2.9, TS3.4, TS3.5, TS3.6, TS3.9, TS4.4, TS4.7, TS4.9, TS5.4, TS5.5, TS5.7, TS5.9, TS6.4, TS6.5, TS6.9, TS7.4, TS7.9, U1.16, U1.30, U1.31, U1.38, U1.51, U1.61, U1.71, U1.83, U1.94, U1.107, U1.120, U1.130, U1.143, U2.2, U2.9, U3.2, U3.9, UA5.1, Y2.2
I2C_1_SCL: AS8.3, H1.21
I2C_1_SDA: AS8.7, H1.22
I2C_2_SCL: AS9.3, H2.21
I2C_2_SDA: AS9.7, H2.22
unnamed: C27.1, D1.1, Q1.4
unnamed: C28.1, Q1.6
unnamed: C50.2, R47.1, Y1.2
unnamed: C51.1, EF1.18
unnamed: C52.1, EF2.18
unnamed: C60.1, D2.1, Q2.4
unnamed: C61.1, D3.1, Q3.4
unnamed: C64.2, R77.2, R79.2
unnamed: C65.2, R78.2, R80.2
unnamed: C66.1, Q2.6
unnamed: C67.1, Q3.6
unnamed: EF1.3, R63.2, R64.1
unnamed: EF1.14, R50.2, R51.1
unnamed: EF1.15, R51.2, R52.1
unnamed: EF1.17, R59.2
unnamed: EF2.3, R65.2, R66.1
unnamed: EF2.14, R54.2, R55.1
unnamed: EF2.15, R55.2, R56.1
unnamed: EF2.17, R60.2
unnamed: ESD1.1, ESD1.14, JC1.2, R41.1
unnamed: ESD1.5, JC1.1, R58.2
unnamed: ESD1.6, ESD1.9, JC1.7, R45.1
unnamed: ESD1.7, ESD1.8, JC1.8, R46.1
unnamed: ESD1.4, ESD1.11, JC1.5, R44.1
unnamed: ESD1.3, ESD1.12, JC1.4, R43.1
unnamed: ESD1.2, ESD1.13, JC1.3, R42.1
unnamed: F1.1, UA5.2
unnamed: F2.1, UA5.3
unnamed: FB1.1, L1.2
unnamed: FB2.1, R58.1
unnamed: LG1.4, Q2.3, Q3.3, R76.1
unnamed: R5.1, U1.138
unnamed: R6.1, U1.124
unnamed: R7.1, U1.22
unnamed: R8.1, U1.63
unnamed: R9.1, U1.65
unnamed: R12.2, U1.41
unnamed: R13.2, U1.74
unnamed: R57.2, Y2.1
unnamed: R69.1, U2.4
unnamed: R70.1, U2.1
unnamed: R71.1, U3.4
unnamed: R72.1, U3.1
unnamed: R73.1, U2.8
unnamed: R74.1, U3.8
SPI_1_CS1: AS10.3, H1.9
SPI_1_CS2: AS1.15, H1.7
SPI_1_MISO: AS10.11, H1.12
SPI_1_MOSI: AS10.7, H1.10
SPI_1_SCK: AS10.15, H1.11
SPI_2_CS1: AS11.3, H2.9
SPI_2_CS2: AS2.15, H2.7
SPI_2_MISO: AS11.11, H2.12
SPI_2_MOSI: AS11.7, H2.10
SPI_2_SCK: AS11.15, H2.11
SUP_3V3: EF1.9, EF1.10, EF1.11, EF1.12, EF1.13, F1.2, H2.27, H2.28, R50.1
SUP_5V: EF2.9, EF2.10, EF2.11, EF2.12, EF2.13, F2.2, H2.25, H2.26, R54.1
UART_1_CTS: AS14.7, H1.14
UART_1_RST: AS14.11, H1.16
UART_1_RX: AS14.15, H1.15
UART_1_TX: AS14.3, H1.13
UART_2_CTS: AS15.7, H2.14
UART_2_RST: AS15.11, H2.16
UART_2_RX: AS15.15, H2.15
UART_2_TX: AS15.3, H2.13
UART_RCS_1_CTS: AS12.7, H1.18
UART_RCS_1_RST: AS12.11, H1.20
UART_RCS_1_RX: AS12.15, H1.19
UART_RCS_1_TX: AS12.3, H1.17
UART_RCS_2_CTS: AS13.7, H2.18
UART_RCS_2_RST: AS13.11, H2.20
UART_RCS_2_RX: AS13.3, H2.19
UART_RCS_2_TX: AS13.15, H2.17
USER_1_1: AS1.3, H1.5
USER_1_2: AS1.7, H1.6
USER_1_4: AS1.11, H1.8
USER_2_1: AS2.3, H2.5
USER_2_2: AS2.7, H2.6
USER_2_4: AS2.11, H2.8
USER_3_1: AS3.15, H1.39
USER_3_2: AS3.3, H1.40
USER_3_3: AS3.11, H1.41
USER_3_4: AS3.7, H1.42
USER_4_1: AS4.3, H2.39
USER_4_2: AS4.11, H2.40
USER_4_3: AS4.7, H2.41
USER_4_4: AS4.15, H2.42
USER_5_1: AS5.15, H1.43
USER_5_2: AS5.7, H1.44
USER_5_3: AS5.3, H1.45
USER_5_4: AS5.11, H1.46
USER_6_1: AS6.15, H2.43
USER_6_2: AS6.3, H2.44
USER_6_3: AS6.11, H2.47
USER_6_4: AS6.7, H2.48

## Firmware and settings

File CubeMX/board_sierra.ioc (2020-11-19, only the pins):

Mcu.UserName=STM32L496ZGTx
PA0.GPIO_Label=QSPI_CS1
PA0.Signal=GPIO_Output
PA1.GPIO_Label=QSPI_CS2
PA1.Signal=GPIO_Output
PA10.GPIO_Label=UART1_RX
PA10.Signal=USART1_RX
PA11.GPIO_Label=UART1_CTS
PA11.Signal=USART1_CTS
PA12.GPIO_Label=UART1_RST
PA12.Signal=USART1_RTS
PA2.GPIO_Label=QSPI_CS3
PA2.Signal=QUADSPI_BK1_NCS
PA3.GPIO_Label=SPI1_CS3
PA3.Signal=GPIO_Output
PA4.GPIO_Label=SPI1_CS2
PA4.Signal=GPIO_Output
PA5.GPIO_Label=SPI1_SCK
PA5.Signal=SPI1_SCK
PA6.GPIO_Label=SPI1_MISO
PA6.Signal=SPI1_MISO
PA7.GPIO_Label=SPI1_MOSI
PA7.Signal=SPI1_MOSI
PA8.GPIO_Label=USER_SPI2_EN
PA8.Signal=GPIO_Output
PA9.GPIO_Label=UART1_TX
PA9.Signal=USART1_TX
PB0.GPIO_Label=USER4_2
PB0.Signal=GPIO_Input
PB1.GPIO_Label=USER3_2
PB1.Signal=GPIO_Input
PB10.GPIO_Label=I2C4_SCL
PB10.Signal=I2C4_SCL
PB11.GPIO_Label=I2C4_SDA
PB11.Signal=I2C4_SDA
PB12.GPIO_Label=I2C4_EN
PB12.Signal=GPIO_Output
PB13.GPIO_Label=SPI2_SCK
PB13.Signal=SPI2_SCK
PB14.GPIO_Label=SPI2_MISO
PB14.Signal=SPI2_MISO
PB15.GPIO_Label=SPI2_MOSI
PB15.Signal=SPI2_MOSI
PB2.GPIO_Label=USER3_4
PB2.Signal=GPIO_Input
PB5.GPIO_Label=CAN2_RX
PB5.Signal=CAN2_RX
PB6.GPIO_Label=CAN2_TX
PB6.Signal=CAN2_TX
PB7.GPIO_Label=UART4_CTS
PB7.Signal=UART4_CTS
PB8.GPIO_Label=CAN1_RX
PB8.Signal=CAN1_RX
PB9.GPIO_Label=CAN1_TX
PB9.Signal=CAN1_TX
PC0.GPIO_Label=SPI1_HOLD
PC0.Signal=GPIO_Output
PC1.GPIO_Label=SPI1_WP
PC1.Signal=GPIO_Output
PC10.GPIO_Label=UART4_TX
PC10.Signal=UART4_TX
PC11.GPIO_Label=UART4_RX
PC11.Signal=UART4_RX
PC12.GPIO_Label=UART5_TX
PC12.Signal=UART5_TX
PC2.GPIO_Label=EF2_CUR
PC2.Signal=ADCx_IN3
PC3.GPIO_Label=EF1_CUR
PC3.Signal=ADCx_IN4
PC4.GPIO_Label=SPI1_CS_1
PC4.Signal=GPIO_Output
PC5.GPIO_Label=USER4_4
PC5.Signal=GPIO_Input
PC6.GPIO_Label=SPI2_CS1
PC6.Signal=GPIO_Output
PC7.GPIO_Label=SPI3_CS1
PC7.Signal=GPIO_Output
PC8.GPIO_Label=USER_SPI3_EN
PC8.Signal=GPIO_Output
PC9.GPIO_Label=USER1_EN
PC9.Signal=GPIO_Output
PD0.GPIO_Label=USER2_EN
PD0.Signal=GPIO_Output
PD1.GPIO_Label=USER5_EN
PD1.Signal=GPIO_Output
PD10.GPIO_Label=UART3_EN
PD10.Signal=GPIO_Output
PD11.GPIO_Label=UART3_CTS
PD11.Signal=USART3_CTS
PD12.GPIO_Label=UART3_RST
PD12.Signal=USART3_RTS
PD13.GPIO_Label=CAN2_EN
PD13.Signal=GPIO_Output
PD14.GPIO_Label=I2C3_EN
PD14.Signal=GPIO_Output
PD15.GPIO_Label=CAN1_EN
PD15.Signal=GPIO_Output
PD2.GPIO_Label=UART5_RX
PD2.Signal=UART5_RX
PD3.GPIO_Label=UART2_CTS
PD3.Signal=USART2_CTS
PD4.GPIO_Label=UART2_RST
PD4.Signal=USART2_RTS
PD5.GPIO_Label=UART2_TX
PD5.Signal=USART2_TX
PD6.GPIO_Label=UART2_RX
PD6.Signal=USART2_RX
PD7.GPIO_Label=I2C2_EN
PD7.Signal=GPIO_Output
PD8.GPIO_Label=UART3_TX
PD8.Signal=USART3_TX
PD9.GPIO_Label=UART3_RX
PD9.Signal=USART3_RX
PE0.GPIO_Label=USER6_2
PE0.Signal=GPIO_Input
PE1.GPIO_Label=USER6_4
PE1.Signal=GPIO_Input
PE10.GPIO_Label=FAULT
PE10.Signal=GPIO_Output
PE11.GPIO_Label=CPU_EN
PE11.Signal=GPIO_Output
PE12.GPIO_Label=MODE
PE12.Signal=GPIO_Input
PE13.GPIO_Label=WATCHDOG
PE13.Signal=GPIO_Input
PE14.GPIO_Label=SYNC
PE14.Signal=GPIO_Input
PE15.GPIO_Label=GLO_EN
PE15.Signal=GPIO_Output
PE2.GPIO_Label=USER6_1
PE2.Signal=GPIO_Input
PE3.GPIO_Label=USER5_3
PE3.Signal=GPIO_Input
PE4.GPIO_Label=USER5_1
PE4.Signal=GPIO_Input
PE5.GPIO_Label=USER6_3
PE5.Signal=GPIO_Input
PE6.GPIO_Label=USER4_3
PE6.Signal=GPIO_Input
PE7.GPIO_Label=USER2_1
PE7.Signal=GPIO_Output
PE8.GPIO_Label=USER2_4
PE8.Signal=GPIO_Input
PE9.GPIO_Label=SPI2_CS2
PE9.Signal=GPIO_Input
PF0.GPIO_Label=I2C2_SDA
PF0.Signal=I2C2_SDA
PF1.GPIO_Label=I2C2_SCL
PF1.Signal=I2C2_SCL
PF10.GPIO_Label=QSPI_CLK
PF10.Signal=QUADSPI_CLK
PF11.GPIO_Label=USER3_3
PF11.Signal=GPIO_Input
PF12.GPIO_Label=USER3_1
PF12.Signal=GPIO_Input
PF13.GPIO_Label=USER1_1
PF13.Signal=GPIO_Output
PF14.GPIO_Label=SPI3_CS2
PF14.Signal=GPIO_Input
PF15.GPIO_Label=USER1_2
PF15.Signal=GPIO_Input
PF3.GPIO_Label=USER4_1
PF3.Signal=GPIO_Input
PF4.GPIO_Label=USER5_2
PF4.Signal=GPIO_Input
PF5.GPIO_Label=USER5_4
PF5.Signal=GPIO_Input
PF6.GPIO_Label=QSPI_BK1_IO3
PF6.Signal=QUADSPI_BK1_IO3
PF7.GPIO_Label=QSPI_BK1_IO2
PF7.Signal=QUADSPI_BK1_IO2
PF8.GPIO_Label=QSPI_BK1_IO0
PF8.Signal=QUADSPI_BK1_IO0
PF9.GPIO_Label=QSPI_BK1_IO1
PF9.Signal=QUADSPI_BK1_IO1
PG0.GPIO_Label=USER1_4
PG0.Signal=GPIO_Input
PG1.GPIO_Label=USER2_2
PG1.Signal=GPIO_Input
PG10.GPIO_Label=SPI3_MISO
PG10.Signal=SPI3_MISO
PG11.GPIO_Label=SPI3_MOSI
PG11.Signal=SPI3_MOSI
PG12.GPIO_Label=USER4_EN
PG12.Signal=GPIO_Output
PG15.GPIO_Label=USER3_EN
PG15.Signal=GPIO_Output
PG2.GPIO_Label=UART2_EN
PG2.Signal=GPIO_Output
PG3.GPIO_Label=UART4_EN
PG3.Signal=GPIO_Output
PG4.GPIO_Label=UART1_EN
PG4.Signal=GPIO_Output
PG5.GPIO_Label=SPI3_EN
PG5.Signal=GPIO_Output
PG6.GPIO_Label=SPI2_EN
PG6.Signal=GPIO_Output
PG7.GPIO_Label=I2C3_SCL
PG7.Signal=I2C3_SCL
PG8.GPIO_Label=I2C3_SDA
PG8.Signal=I2C3_SDA
PG9.GPIO_Label=SPI3_SCK
PG9.Signal=SPI3_SCK
PH3-BOOT0.GPIO_Label=BOOT
PH3-BOOT0.Signal=GPIO_Input

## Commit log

2020-11-24 sync with library
    [board_sierra.kicad_pcb, board_sierra.sch]
2020-11-24 exports added
    [header_pinout.ods]
2020-11-25 pinout doc. update
    [header_pinout.ods]
2021-02-16 L1 to 0603
    [BOM_comparation.xlsx, BOM_mouser_qualifiedMain.xls, BOM_mouser_unqualifiedMain.xls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]
2021-02-17 BOM generation
    [BOM_comparation.xlsx, BOM_mouser_qualifiedMain.xls, BOM_mouser_unqualifiedMain.xls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]
2021-02-28 power management update
    [board_sierra.kicad_pcb, board_sierra.sch]
2021-02-28 cosmetic update
    [board_sierra.kicad_pcb, board_sierra.sch]
2021-02-28 BOM update
    [BOM_comparation.xlsx, BOM_mouser_qualifiedMain.xls, BOM_mouser_unqualifiedMain.xls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]
2021-03-01 libraries updated
    [board_sierra.kicad_pcb, board_sierra.sch]
2021-03-03 MCU resin hole added
    [board_sierra.kicad_pcb, board_sierra.sch]
2021-03-03 gerbers exported
    [board_sierra.kicad_pcb]
2021-03-23 schem. cosmetic updates
    [board_sierra-B_CrtYd.gbr, board_sierra-B_Cu.gbr, board_sierra-B_Fab.gbr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]
